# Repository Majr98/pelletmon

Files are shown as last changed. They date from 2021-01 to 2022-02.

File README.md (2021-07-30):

# WHAT AND WHY?

Our old boiler was previously connected to my IoT system. After replacing the boiler with a new one, we no longer have this option. So why not introduce it to a new boiler?

# THE TARGET

The goal of the project is to reverse engineer the CAN communication of the new boiler and expose real-time data to the IoT. By the way, the HC-SR04 sensor will measure the fuel level in the tank.

# DESIGN

The project will have its own PCB. Communication with the outside world will be carried out using ESP32 and fuel level measurement using HC-SR04. The SN65HVD230 chip will be used as the CAN transceiver. The software will be written in the Arduino environment in C ++ and will be powered with my IoT framework - ksIotFrameworkLib.

# KNOWN ISSUES

## HARDWARE

### rev 0.01a-0.01c
- GPIO0 is directly connected to SWITCH (S1), avoid setting direct HIGH state at that pin from software, because it can result in short circuit when pressing S1, as it will tie IO0 to ground directly.

## SOFTWARE
- <s>Hardcoded CAN support.</s> (now using VideNet, which is universal)
- <s>Sometimes at boot sends "zero" values to MQTT.</s>
- No support for fuel level sensor. (it was previously planned, but VideNet gives info about fuel usage)

# PICS
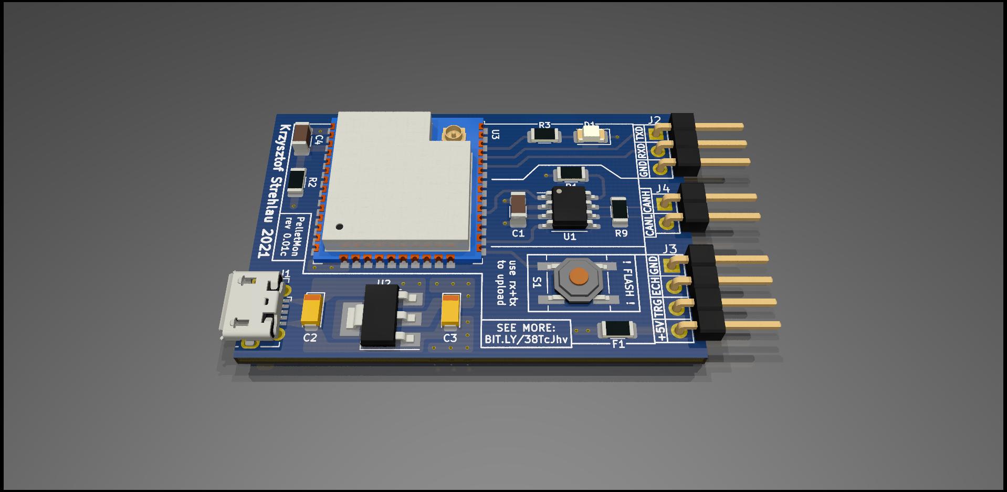
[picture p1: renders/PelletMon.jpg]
Board design top

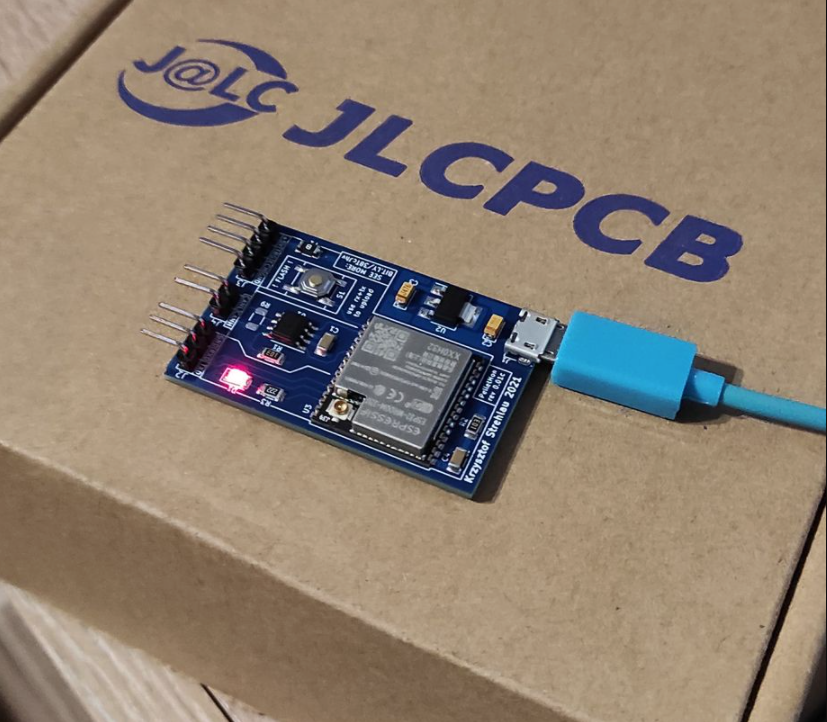
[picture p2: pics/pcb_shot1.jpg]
Device 1 Device 2

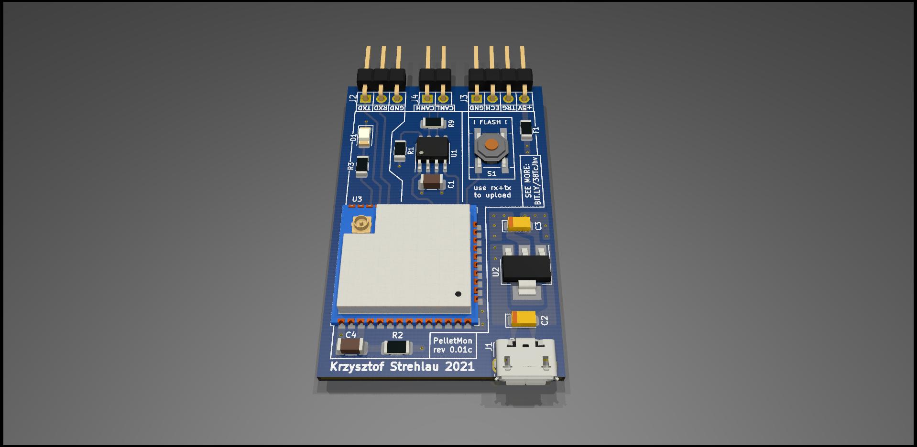
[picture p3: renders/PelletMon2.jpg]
Board design right

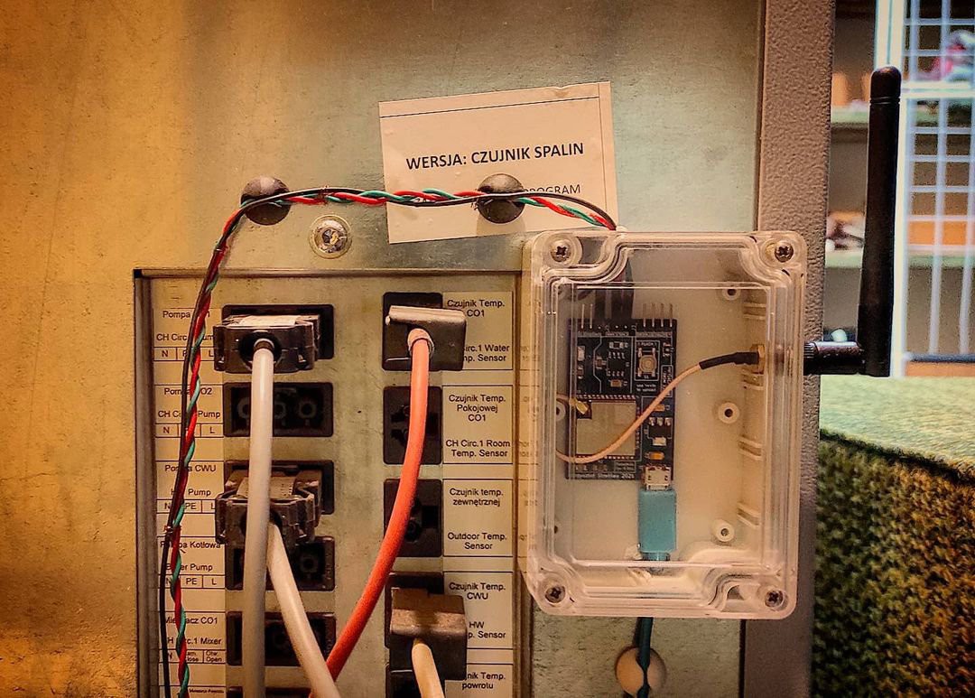
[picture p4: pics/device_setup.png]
Device 2 Device 1


# Special thanks
- M-Works [ https://m-works.net/ ]
- Robert Labuz.

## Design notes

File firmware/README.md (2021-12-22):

# Firmware for PelletMon device

This directory contains code for PelletMon device. Written in C++ for ESP32, based on ksIotFrameworkLib and Arduino environment.
Use Visual Studio with Visual Micro plugin to open project properly. ESP32 environment must be installed within Arduino board manager. 
Requires ESP32_CAN library with CAN Common + ksIotFrameworkLib dependencies.

* Temperature readings based on reverse engineered CAN protocol.
* Vide-Net support based on [awesome work done by Kem Klattrup @kematic](https://github.com/kematic).
* No support for Pellet (fuel) level sensor that was planned at beggining (no time for development, Vide-Net protocol might handle that).

## Features
* Based on ksIotFrameworkLib, simple, clear and responsive non-blocking code.
* WiFi settings support (via cap portal with WiFiManager library).
* Reading kettle state (kettle temperature, hot water temperature, power etc.)
* Remote kettle control (heating modes, disable/enable controller etc.).
* Synchronization with MQTT broker.

## Components

PelletMon app is divided into components, that handle specific tasks.
* VideNetClient - handles VideNet CAN protocol (reads message from queue in loop but is also able to send messages), handles VideNet communication also as well.

## Other classes
* VideNet - contains message classes and general protocol implementation for VideNet. Used by EstymaClient to handle VideNet specific messages.
* Board - some low-level code handling CAN bus is placed inside board.cpp.

## References and special thanks
* [Installation manual for Estyma based kettle (PL)](https://www.estyma.pl/wp-content/uploads/2018/11/Przewodnik-instalatora.pdf)
* [Vide-Net documentation (by Kem Klattrup)](https://github.com/kematic/pelle/wiki/Vide.Net-Bia24)
* [CAN-Network documentation (by Kem Klattrup)](https://github.com/kematic/pelle/wiki/CAN-network)
* [Curve Expert creators for awesome tool](https://www.curveexpert.net/)
* [CAN Monitor contributors for awesome tool](https://github.com/tixiv/CAN-Monitor-qt)
* Robert Labuz for his awesome support.
* Damian Nowakowski for being my rubber duck.
* Patryk Pietruszka for dissucssing a lot of problems.
* Damian Kwolek for service hosting.

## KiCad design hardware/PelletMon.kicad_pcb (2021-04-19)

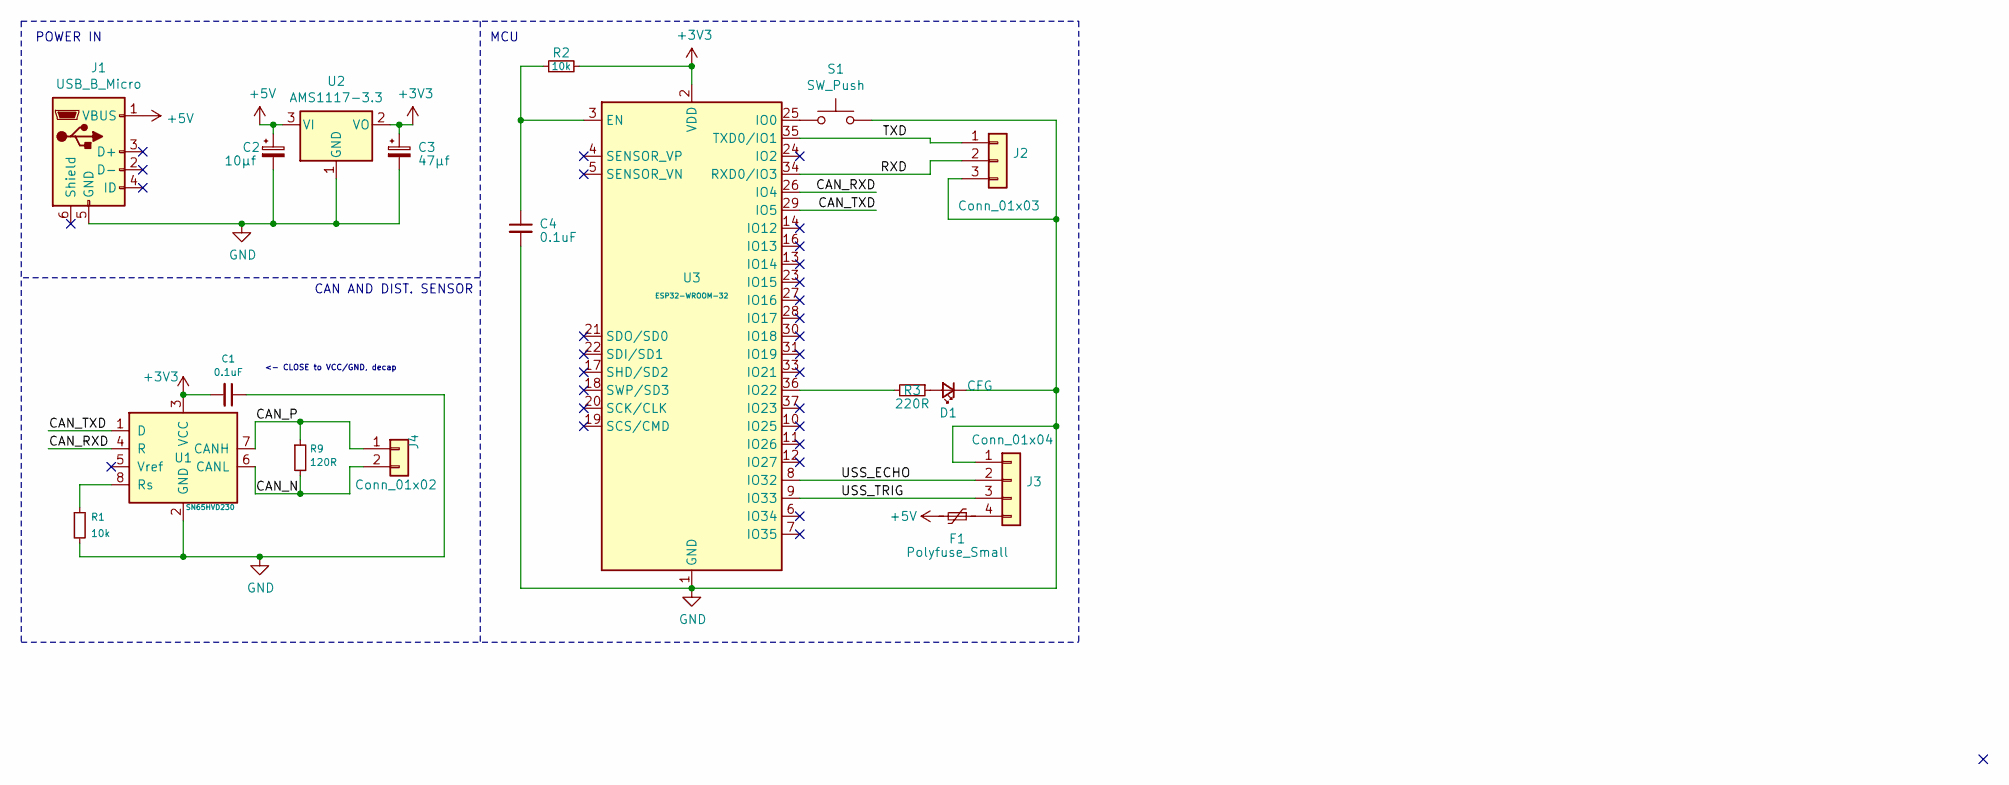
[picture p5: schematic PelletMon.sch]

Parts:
C1: 0.1uF; C_1206_3216Metric
C2: 10µf; CP_EIA-3216-10_Kemet-I; LCSC C126946
C3: 47µf; CP_EIA-3216-10_Kemet-I; LCSC C126946
C4: 0.1uF; C_1206_3216Metric; LCSC C126946
D1: CFG; LED_1206_3216Metric; LCSC C375459
F1: Polyfuse_Small; R_1206_3216Metric
J1: USB_B_Micro; USB_Micro-B_Molex-105017-0001; LCSC C132563
J2: Conn_01x03; PinHeader_1x03_P2.54mm_Vertical
J3: Conn_01x04; PinHeader_1x04_P2.54mm_Vertical
J4: Conn_01x02; PinHeader_1x02_P2.54mm_Vertical
R1: 10k; R_1206_3216Metric
R2: 10k; R_1206_3216Metric; LCSC C1489
R3: 220R; R_1206_3216Metric; LCSC C17948
R9: 120R; R_1206_3216Metric
S1: SW_Push; SW_SPST_B3SL-1022P
U1: SN65HVD230; SOIC-8_3.9x4.9mm_P1.27mm
U2: AMS1117-3.3; SOT-223-3_TabPin2; LCSC C6186
U3: ESP32-WROOM-32; ESP32-WROOM-32U

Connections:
+3V3: C1.2, C3.1, R2.2, U1.3 (VCC), U2.2 (VO), U3.2 (VDD)
+5V: C2.1, F1.2, J1.1 (VBUS), U2.3 (VI)
/CAN_N: J4.2, R9.2, U1.6 (CANL)
/CAN_P: J4.1, R9.1, U1.7 (CANH)
/CAN_RXD: U1.4 (R), U3.26 (IO4)
/CAN_TXD: U1.1 (D), U3.29 (IO5)
/RXD: J2.2, U3.34 (RXD0/IO3)
/TXD: J2.1, U3.35 (TXD0/IO1)
/USS_ECHO: J3.2, U3.8 (IO32)
/USS_TRIG: J3.3, U3.9 (IO33)
GND: C1.1, C2.2, C3.2, C4.2, D1.1 (K), J1.5 (GND), J2.3, J3.1, R1.2, S1.2, U1.2 (GND), U2.1 (GND), U3.1 (GND), U3.15 (GND), U3.38 (GND), U3.39 (GND)
unnamed: C4.1, R2.1, U3.3 (EN)
unnamed: D1.2 (A), R3.1
unnamed: F1.1, J3.4
unnamed: R1.1, U1.8 (Rs)
unnamed: R3.2, U3.36 (IO22)
unnamed: S1.1, U3.25 (IO0)

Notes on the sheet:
POWER IN
MCU
CAN AND DIST. SENSOR
<- CLOSE to VCC/GND, decap

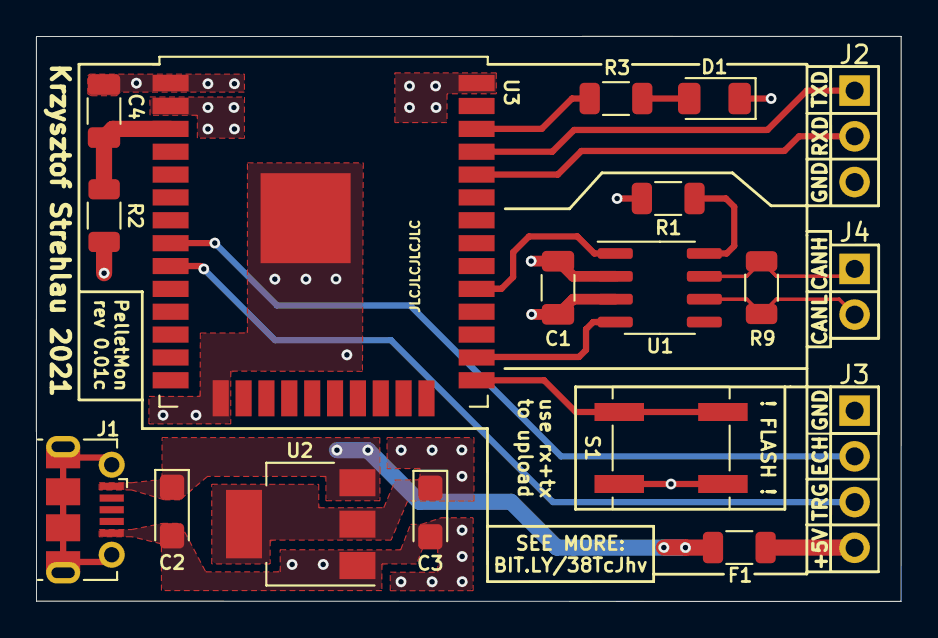
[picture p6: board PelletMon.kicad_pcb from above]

Board: 4 copper layers, 48.0 x 31.4 mm, 18 parts (0 on the bottom side), 17 nets.

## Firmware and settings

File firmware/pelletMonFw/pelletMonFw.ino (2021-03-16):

#include "src/apps/PelletMon/PelletMon.h"
#include "src/apps/config/PelletMonConfig.h"

// the setup function runs once when you press reset or power the board
void setup()
{
	ksf::initKsfFramework();
}

// the loop function runs over and over again until power down or reset
void loop() 
{
	RUN_APP_BLOCKING_LOOPED(PelletMon)
	RUN_APP_BLOCKING_LOOPED(PelletMonConfig)
}

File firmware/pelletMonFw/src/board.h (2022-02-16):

#pragma once

#define STATUS_LED_PIN 22

#define CFG_PUSH_PIN 0

#define CAN_RX_PIN 4
#define CAN_TX_PIN 5

#define HCSR05_ECHO_PIN 32
#define HCSR05_TRIG_PIN 33

#define MQTT_STATUS_UPDATE_INTERVAL 15000

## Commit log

2021-01-06 Hardware design
    [PelletMon.kicad_pcb, PelletMon.sch]
2021-01-06 Update pcb
    [PelletMon.kicad_pcb]
2021-01-07 PCB update
    [PelletMon.kicad_pcb]
2021-01-07 Update gerbers and renders
    [PelletMon.kicad_pcb]
2021-01-07 Last fixes before fab
    [PelletMon.kicad_pcb]
2021-01-07 Before FAB
    [PelletMon.kicad_pcb]
2021-01-12 Minor PCB tweaks
    [PelletMon.kicad_pcb, PelletMon.sch]
2021-01-12 Misc tweaks
    [PelletMon.kicad_pcb]
2021-03-10 Handle CAN in interrupts
2021-04-19 Fix WDT
    [PelletMon.kicad_pcb]
2021-07-26 Add heating mode change support
2021-07-29 No interrupts when sending can message
2021-08-01 Move to better CAN driver
2021-08-09 Switch to esp32_can and can_common
2021-12-16 Change arduino core to run on cpu 0
2021-12-24 Visual project filters
2021-12-27 Proper handling of vector (insert not mixed with erase in same iterator).
2021-12-28 Fix bad condition check.
    [VideNetClient.cpp]
2022-01-04 Update to support latest framework changes
2022-01-06 Fix controller enabled request, minor tweaks in uploadValuesToMqtt method.
    [VideNetClient.cpp]
2022-02-16 Add reset button support
